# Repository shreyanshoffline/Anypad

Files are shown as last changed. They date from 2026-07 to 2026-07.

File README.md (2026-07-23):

# The Anypad ♾️

A custom left-hand gaming macropad that *actually* respects your muscle memory. Built for the Hack Club Hackpad program.

flag-orpheus-left

Most macropads use a rigid ortholinear grid, which is terrible for gaming. If you try to play Minecraft, Fortnite, or Roblox on a square grid, your fingers get confused because normal keyboards have a staggered layout. 

**The Anypad** fixes this. It features a true QWERTY-accurate 0.25U stagger for the WASD movement cluster, a dedicated thumb spacebar, and stacked pinky keys for Shift/Ctrl. Add an OLED screen, a rotary encoder, and an aggressive amount of RGB, and you have the ultimate mini-pad designed to seamlessly swap between gaming, office, and study modes.

>[!CAUTION]
>Below will be very revoulutionary designs and technology that is game-changing, literally

## 📸 The Screenshots

These are some screenshots of the PCB, Schematic, Case, And Complete Build.

### Overall Hackpad
Overall Hackpad

*(Note: Coming soon! After Build)*

### Schematic
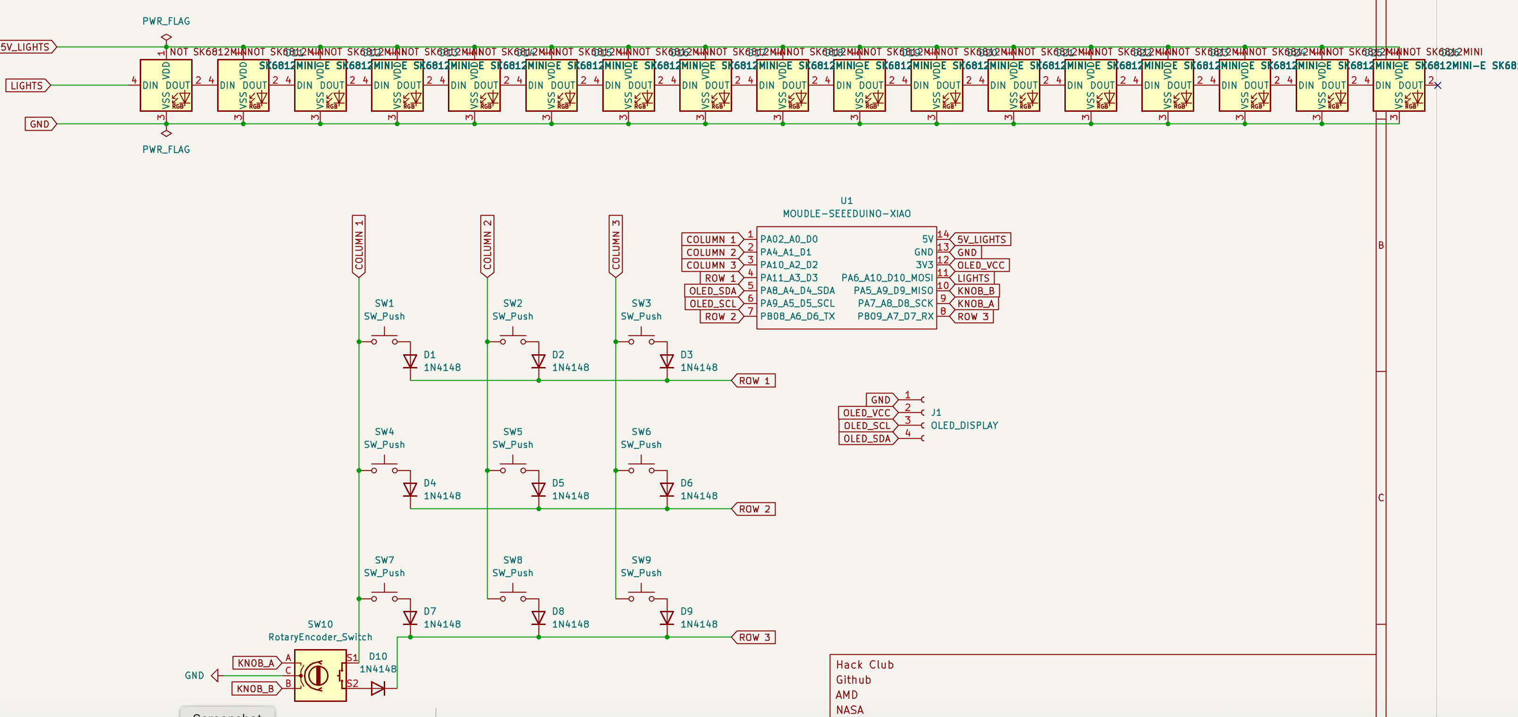
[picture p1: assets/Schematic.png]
Schematic


### PCB Layout
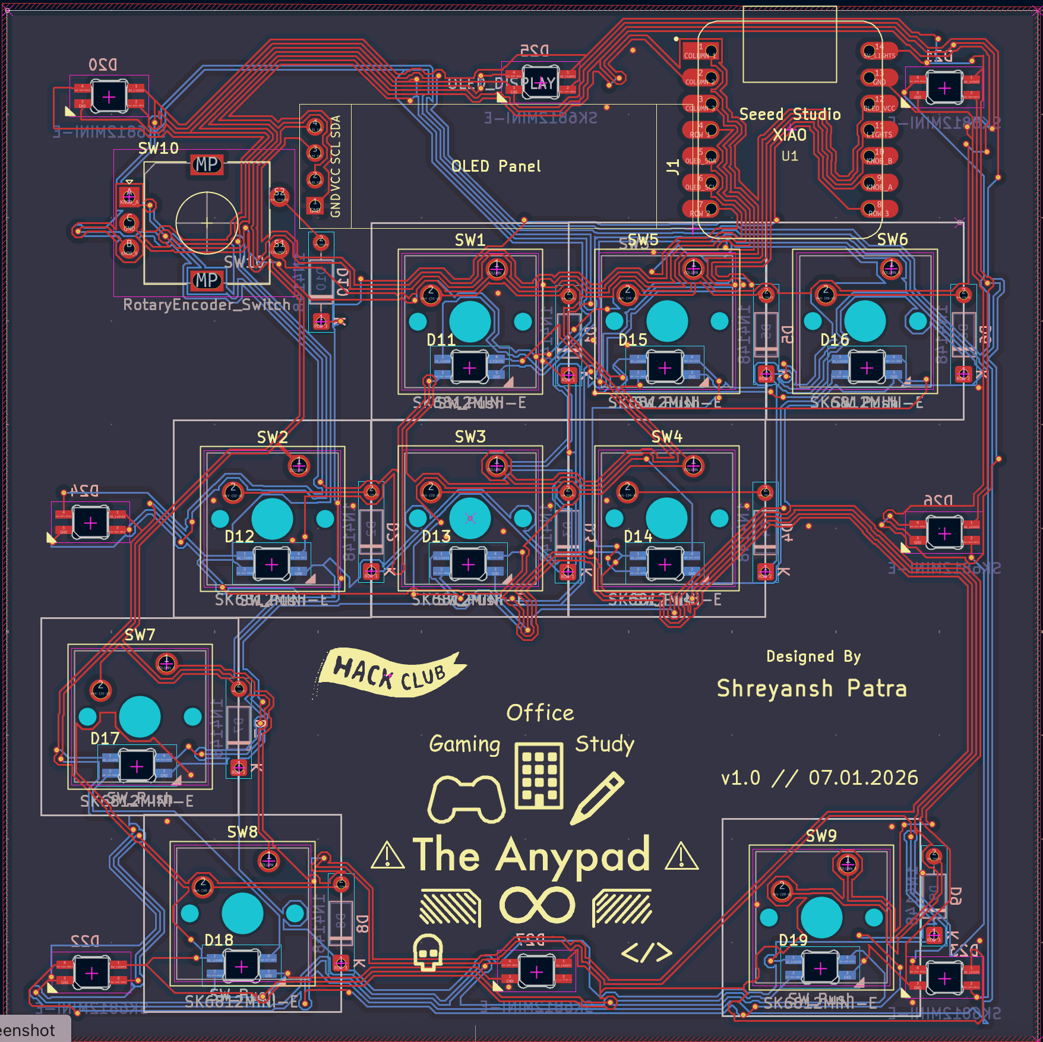
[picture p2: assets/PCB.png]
PCB Layout

>[!NOTE]
>Check out the silkscreen art

### CAD in Fusion360
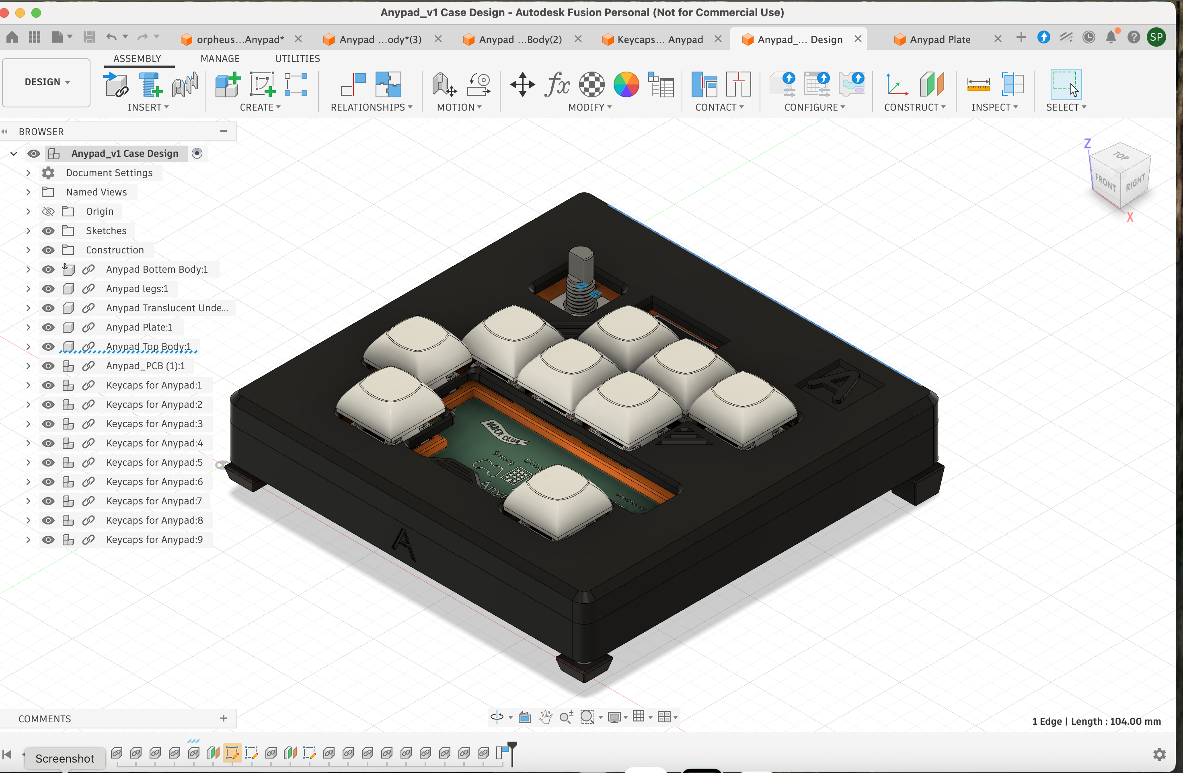
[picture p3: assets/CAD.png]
Case Assembly


---

## ✨ Features
* **Muscle-Memory Layout:** 9 mechanical switches arranged with realistic desktop stagger so you don't miss inputs mid-game or while locked in during work.
* **The Brain:** Powered by The Seeed Studio XIAO RP2040 Microcontroller. Small, But Mighty
* **The Screen:** A 0.91" OLED display to give visual feedback on your current active profile (Gaming 🎮 / Office 🏢 / Study ✏️).
* **The Knob** Instead of using keys to switch inventory slots, or raise and reduce volume the knob allows you to do more while taking less space.

## ✅ Benefits
* **Light, Small, Fast:** Instead of carrying an entire keyboard all you need is a mouse and The Anypad. Easily portable and gives you more desk space.
* **Focus, Study, Game:** Switch between focus modes in the swift turn of a knob. Quickly immerse your self in the gaming world or into optimized work and study shortcuts
* **RGB Everything:** 17 total SK6812 MINI-E addressable LEDs (9 per-key backlights + 8 corner underglows for a seamless desk halo effect). Instantly turns up your vibe
* **Ergonomics Over Symmetry:** The Anypad prioritizes hand comfort over artificial symmetry. While the layout might look like an unusual angle at first glance, it naturally aligns with where your fingers want to rest during long gaming sessions.

## </> Firmware Overview
The Anypad uses QMK for everything

>[!NOTE]
> Via will be added soon for instant flashing and customization

## 🧰 Bill of Materials (BOM)

| Component | Qty | Description |
| :--- | :---: | :--- |
| Seeed XIAO RP2040 | 1 | The Brains of the system, A Mighty little Microcontroller |
| EC11 Rotary Encoder | 1 | Rotating knob, with push-button functionality |
| Encoder Knob | 1 | Fits over the EC11 shaft |
| 0.91" OLED Display | 1 | Standard 4-pin breakout (GND, VCC, SCL, SDA) |
| Reverse Mount SK6812 MINI-E LEDs | 17 | 9 for Keys, 8 for bottom underglow |
| Through-Hole 1N4148 Diodes | 9 | For the 3x3 anti-ghosting matrix |
| Custom PCB (In /PCB)| 1 | Holds and connects all electrical components |
| Custom 3D Printed Case (In /Production)| 1 | Top plate + bottom enclosure |
| Blank White DSA Keycaps | 9 | 1U caps, Smooth and blank |
| MX-Style Keyswitches | 9 | The Nice Clicky Kind |
| M3x16mm screws | 4 | Tiny Screws That hold everything together |
| M3x5mx4mm Brass Heatset Inserts | 4 | Brass treads that makes the case re-openable |
>[!NOTE]
> You may also need a solder, soldering iron and other soldering accessories for completing the build

>[!TIP]
> You can get all the materials for free or bundled from the Hackpad Kit by Hack club. 

## 🧠 Behind the Hardware (The Wiring Matrix)

To make everything fit on the XIAO's extremely limited edge pins, the 9 keys are wired into a standard 3x3 diode matrix (using only 6 pins). 

This is a basic efficient layout that frees up the remaining pins perfectly for the OLED (2 pins), the Rotary Encoder (2 pins), and a single data line chained through all 17 LEDs without needing to resort to hidden pads or larger microcontrollers. 

---
> Designed by [shreyanshoffline](https://github.com/shreyanshoffline) for The Stardance Challenge by Hack Club, NASA, AMD, and Github.

unnamed

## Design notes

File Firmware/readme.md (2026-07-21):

# The Anypad

the_anypad

*A short description of the keyboard/project*

* Keyboard Maintainer: [Shreyansh Patra](https://github.com/shreyanshoffline)
* Hardware Supported: *The PCBs, controllers supported*
* Hardware Availability: *Links to where you can find this hardware*

Make example for this keyboard (after setting up your build environment):

    make the_anypad:default

Flashing example for this keyboard:

    make the_anypad:default:flash

See the [build environment setup](https://docs.qmk.fm/#/getting_started_build_tools) and the [make instructions](https://docs.qmk.fm/#/getting_started_make_guide) for more information. Brand new to QMK? Start with our [Complete Newbs Guide](https://docs.qmk.fm/#/newbs).

## Bootloader

Enter the bootloader in 3 ways:

* **Bootmagic reset**: Hold down the key at (0,0) in the matrix (usually the top left key or Escape) and plug in the keyboard
* **Physical reset button**: Briefly press the button on the back of the PCB - some may have pads you must short instead
* **Keycode in layout**: Press the key mapped to `QK_BOOT` if it is available

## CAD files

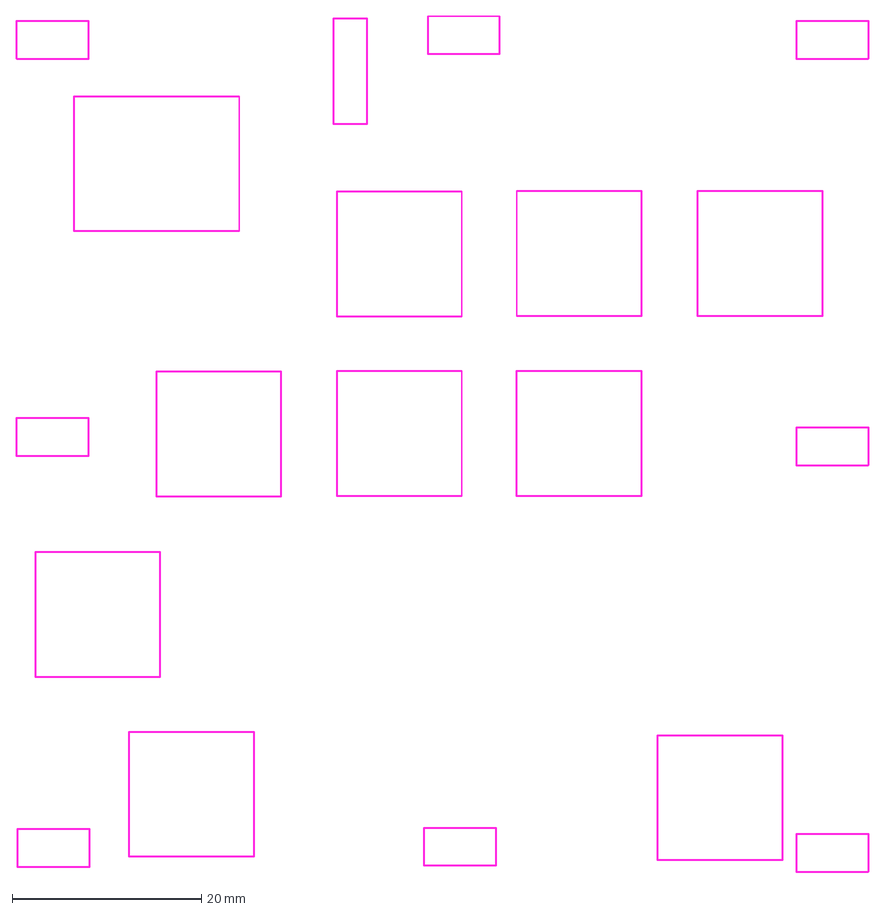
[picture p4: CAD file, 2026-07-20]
PCB/Drawings, Diagrams, and 3d Files of PCB/Anypad-F_Courtyard.dxf
90.2 x 90.5 mm

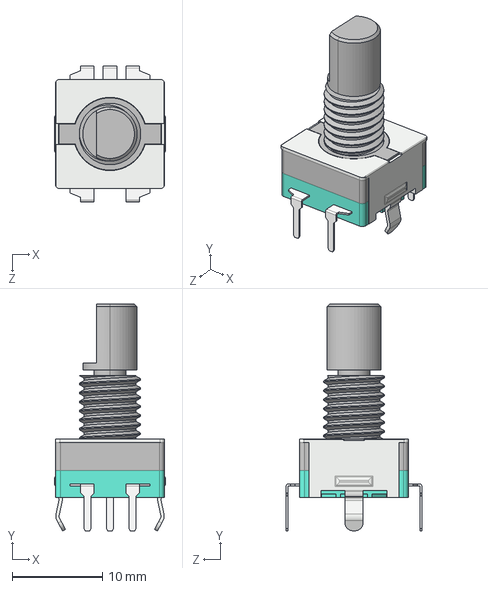
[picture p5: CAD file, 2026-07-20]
PCB/Files for 3d viewer/EC11_Rotary_Encoder.STEP
12.3 x 25.1 x 15.0 mm

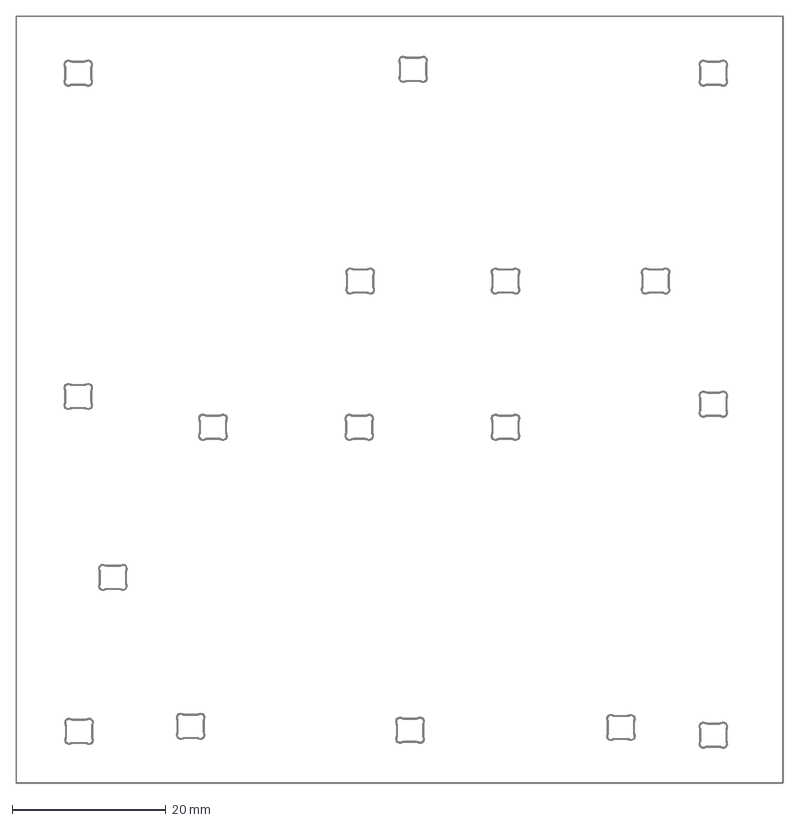
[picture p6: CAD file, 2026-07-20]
PCB/Drawings, Diagrams, and 3d Files of PCB/Anypad-Edge_Cuts.dxf
99.6 x 99.6 mm

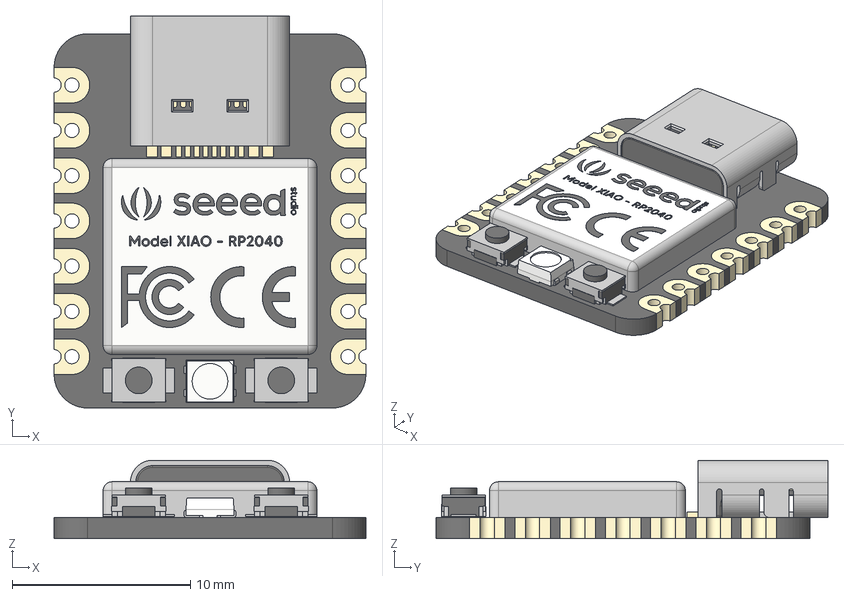
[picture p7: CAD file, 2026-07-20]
PCB/Files for 3d viewer/Seeed Studio XIAO RP2040 v26.step
17.5 x 22.0 x 4.40 mm
type-c v2
smd_button v3
DOUT
DIN
VSS
VDD
smd_button v3(Mirror)

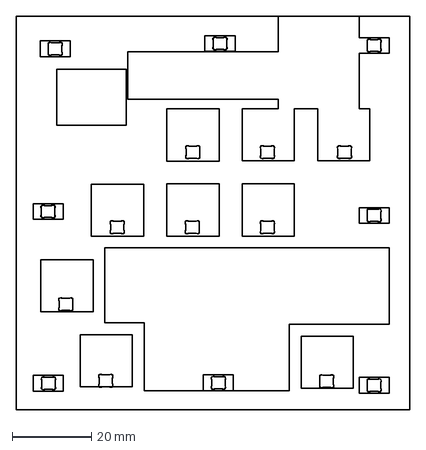
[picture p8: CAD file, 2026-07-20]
PCB/Drawings, Diagrams, and 3d Files of PCB/Anypad_Plate.dxf
99.6 x 99.6 mm

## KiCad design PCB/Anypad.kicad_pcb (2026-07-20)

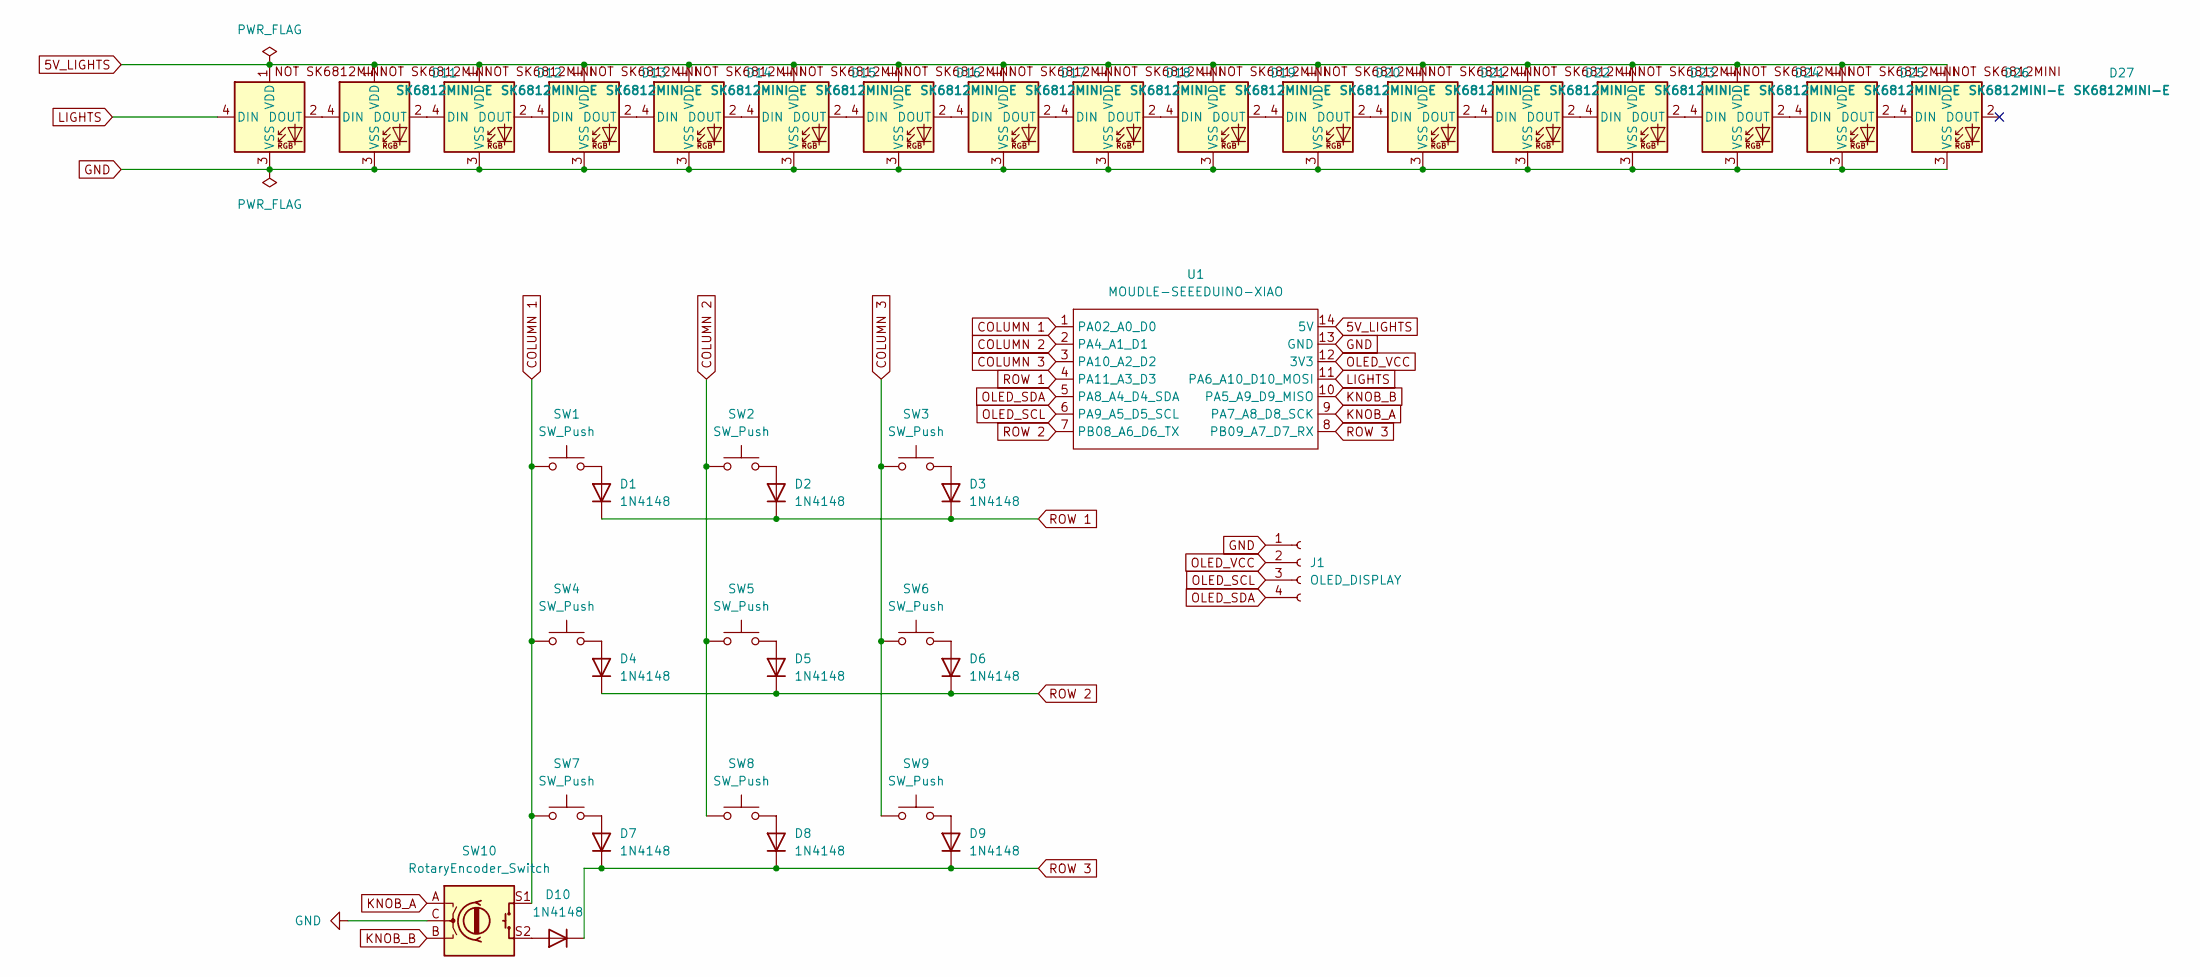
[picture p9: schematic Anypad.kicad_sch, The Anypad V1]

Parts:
D1, D2, D3, D4, D5, D6, D7, D8, D9, D10: 1N4148; D_DO-35_SOD27_P7.62mm_Horizontal
D11, D12, D13, D14, D15, D16, D17, D18, D19, D20, D21, D22, D23, D24, D25, D26, D27: SK6812MINI-E; SK6812MINI-E_fixed
J1: OLED_DISPLAY; SSD1306-0.91-OLED-4pin-128x32
SW1, SW2, SW3, SW4, SW5, SW6, SW7, SW8, SW9: SW_Push; SW_Cherry_MX_1.00u_PCB
SW10: RotaryEncoder_Switch; RotaryEncoder_Alps_EC11E-Switch_Vertical_H20mm
U1: MOUDLE-SEEEDUINO-XIAO; XIAO-Generic-Hybrid-14P-2.54-21X17.8MM

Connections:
5V_LIGHTS: D11.1 (VDD), D12.1 (VDD), D13.1 (VDD), D14.1 (VDD), D15.1 (VDD), D16.1 (VDD), D17.1 (VDD), D18.1 (VDD), D19.1 (VDD), D20.1 (VDD), D21.1 (VDD), D22.1 (VDD), D23.1 (VDD), D24.1 (VDD), D25.1 (VDD), D26.1 (VDD), D27.1 (VDD), U1.14 (5V)
COLUMN 1: SW1.1, SW4.1, SW7.1, SW10.S1, U1.1 (PA02_A0_D0)
COLUMN 2: SW2.1, SW5.1, SW8.1, U1.2 (PA4_A1_D1)
COLUMN 3: SW3.1, SW6.1, SW9.1, U1.3 (PA10_A2_D2)
GND: D11.3 (VSS), D12.3 (VSS), D13.3 (VSS), D14.3 (VSS), D15.3 (VSS), D16.3 (VSS), D17.3 (VSS), D18.3 (VSS), D19.3 (VSS), D20.3 (VSS), D21.3 (VSS), D22.3 (VSS), D23.3 (VSS), D24.3 (VSS), D25.3 (VSS), D26.3 (VSS), D27.3 (VSS), J1.1, SW10.C, U1.13 (GND)
KNOB_A: SW10.A, U1.9 (PA7_A8_D8_SCK)
KNOB_B: SW10.B, U1.10 (PA5_A9_D9_MISO)
LIGHTS: D11.4 (DIN), U1.11 (PA6_A10_D10_MOSI)
unnamed: D1.2 (A), SW1.2
unnamed: D2.2 (A), SW2.2
unnamed: D3.2 (A), SW3.2
unnamed: D4.2 (A), SW4.2
unnamed: D5.2 (A), SW5.2
unnamed: D6.2 (A), SW6.2
unnamed: D7.2 (A), SW7.2
unnamed: D8.2 (A), SW8.2
unnamed: D9.2 (A), SW9.2
unnamed: D10.2 (A), SW10.S2
unnamed: D11.2 (DOUT), D12.4 (DIN)
unnamed: D12.2 (DOUT), D13.4 (DIN)
unnamed: D13.2 (DOUT), D14.4 (DIN)
unnamed: D14.2 (DOUT), D15.4 (DIN)
unnamed: D15.2 (DOUT), D16.4 (DIN)
unnamed: D16.2 (DOUT), D17.4 (DIN)
unnamed: D17.2 (DOUT), D18.4 (DIN)
unnamed: D18.2 (DOUT), D19.4 (DIN)
unnamed: D19.2 (DOUT), D20.4 (DIN)
unnamed: D20.2 (DOUT), D21.4 (DIN)
unnamed: D21.2 (DOUT), D22.4 (DIN)
unnamed: D22.2 (DOUT), D23.4 (DIN)
unnamed: D23.2 (DOUT), D24.4 (DIN)
unnamed: D24.2 (DOUT), D25.4 (DIN)
unnamed: D25.2 (DOUT), D26.4 (DIN)
unnamed: D26.2 (DOUT), D27.4 (DIN)
OLED_SCL: J1.3, U1.6 (PA9_A5_D5_SCL)
OLED_SDA: J1.4, U1.5 (PA8_A4_D4_SDA)
OLED_VCC: J1.2, U1.12 (3V3)
ROW 1: D1.1 (K), D2.1 (K), D3.1 (K), U1.4 (PA11_A3_D3)
ROW 2: D4.1 (K), D5.1 (K), D6.1 (K), U1.7 (PB08_A6_D6_TX)
ROW 3: D7.1 (K), D8.1 (K), D9.1 (K), D10.1 (K), U1.8 (PB09_A7_D7_RX)

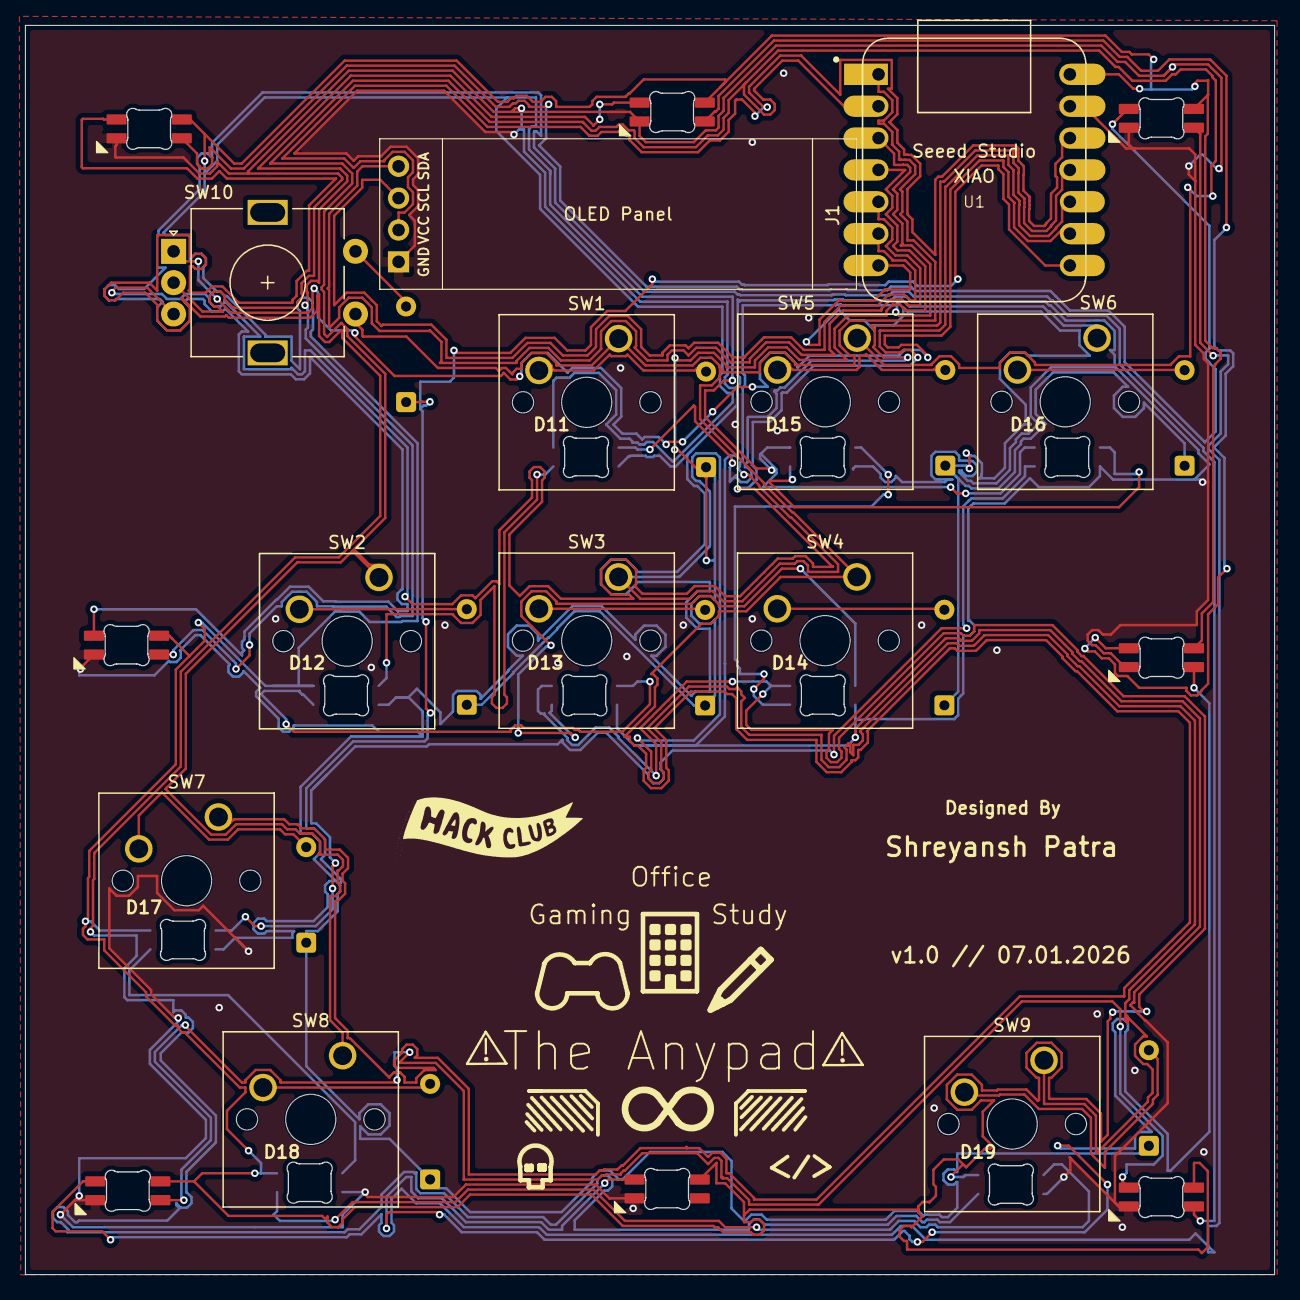
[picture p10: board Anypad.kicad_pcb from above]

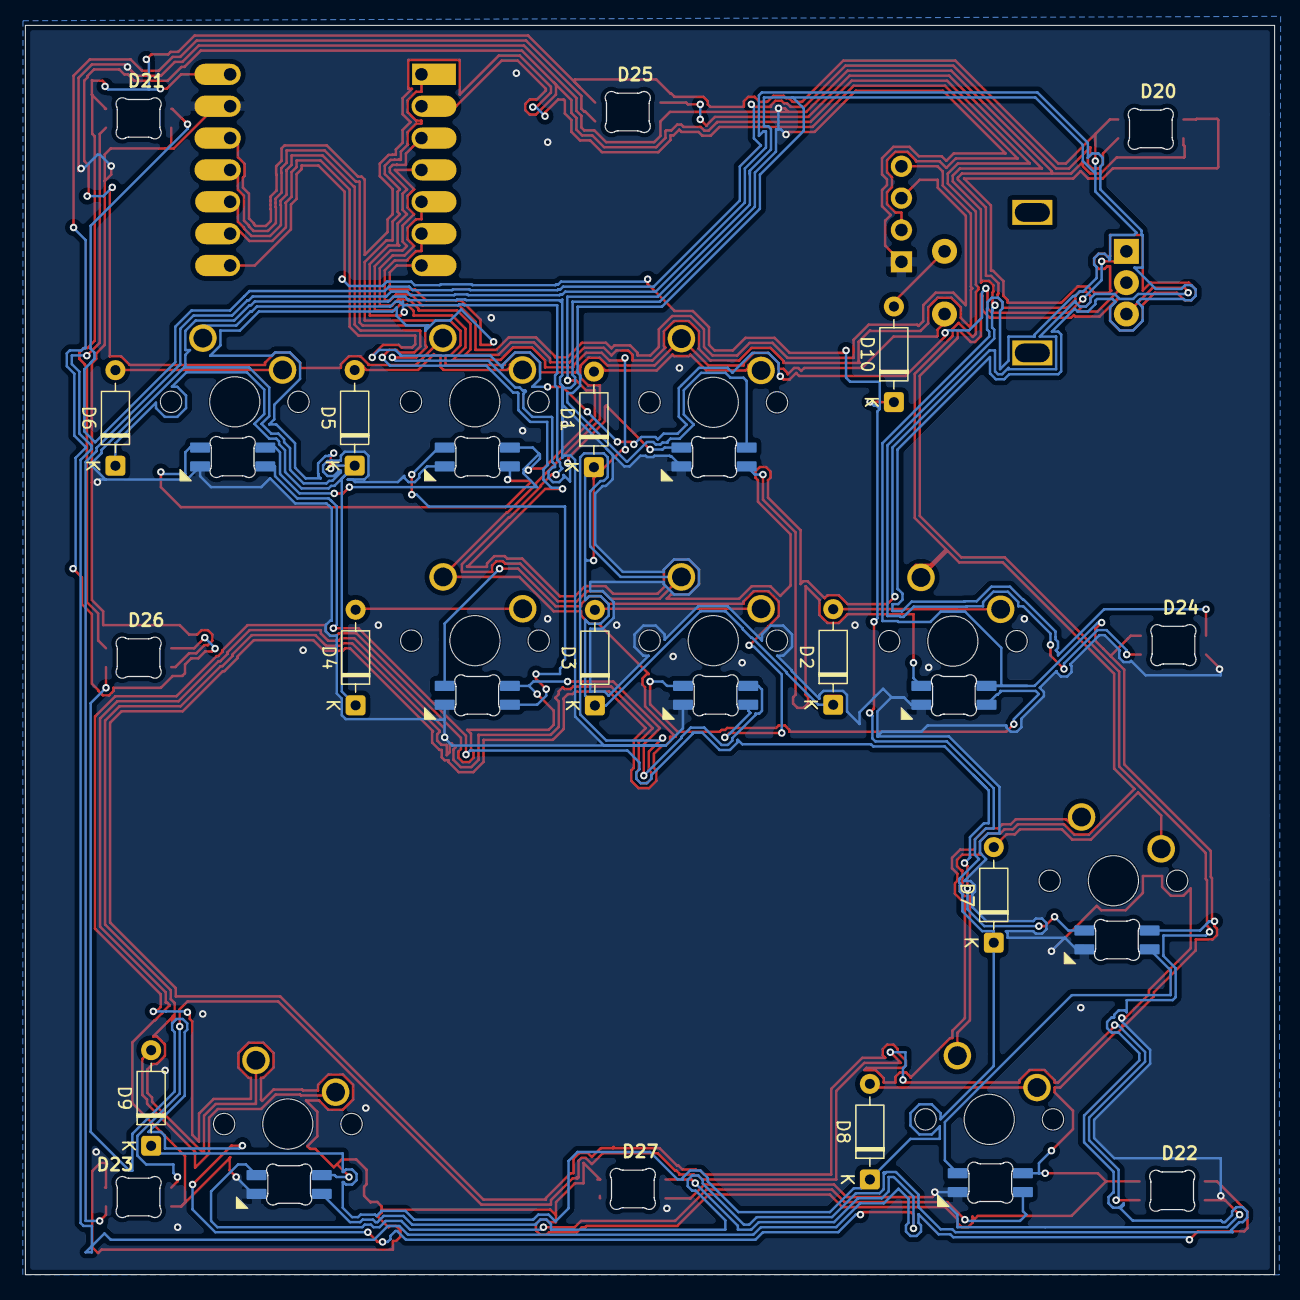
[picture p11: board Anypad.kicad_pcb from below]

Board: 2 copper layers, 99.6 x 99.6 mm, 39 parts (18 on the bottom side), 40 nets.

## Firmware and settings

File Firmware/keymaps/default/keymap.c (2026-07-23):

// Copyright 2026 Shrey Industries
// SPDX-License-Identifier: GPL-2.0-or-later

#include QMK_KEYBOARD_H
#include "animation.h" // Boot animation header

// --- ANIMATION BRIDGE (Resolves symbol mismatches with animation.h) ---
#define anim_frames       frame_allArray
#define TOTAL_ANIM_FRAMES frame_allArray_LEN

// Frame delays in ms (~67ms per frame = 15 FPS across 26 frames)
const uint16_t PROGMEM frame_delays[] = {
    100, 100, 100, 100, 100, 100, 100, 100, 100, 100,
    100, 100, 100, 100, 100, 100, 100, 175, 100, 100,
    100, 100, 100, 100, 100, 200
};

#define OLED_FRAME_BYTES ((128 * 32) / 8)  // width * height / 8 bits-per-byte

// --- LAYERS ---
enum layer_names {
    _OFFICE,
    _STUDY,
    _GAME,
    _SETTINGS
};

// --- CUSTOM KEYCODES ---
enum custom_keycodes {
    AP_GITHUB = SAFE_RANGE,
    AP_VSCODE,
    AP_PORTAL,
    AP_UNDERGLOW,
    AP_LIGHTMATRIX,
    AP_OLEDDISPLAY
};

// --- OLED STYLES ---
typedef enum {
    OLED_STYLE_MENU,      // Default menu list
    OLED_STYLE_VERTICAL,  // Compact vertical layout
    OLED_STYLE_STATS,     // Minimalist stats view
    OLED_STYLE_COUNT      // Total available styles
} oled_style_t;

// --- STATE VARIABLES ---
static bool is_animating_boot = true;
static uint16_t frame_timer = 0;
static uint8_t current_anim_frame = 0;

static bool is_encoder_pressed = false;
static oled_style_t current_oled_style = OLED_STYLE_MENU;

/*
 * PURE ELECTRICAL MATRIX LAYOUT (0-indexed for QMK / 1-indexed in KiCad):
 * Row 0: (0,0) [KiCad R1,C1] | (0,1) [KiCad R1,C2] | (0,2) [KiCad R1,C3]
 * Row 1: (1,0) [KiCad R2,C1] | (1,1) [KiCad R2,C2] | (1,2) [KiCad R2,C3]
 * Row 2: (2,0) [KiCad R3,C1] | (2,1) [KiCad R3,C2] | (2,2) [KiCad R3,C3]
 */

const uint16_t PROGMEM keymaps[][MATRIX_ROWS][MATRIX_COLS] = {
    [_OFFICE] = LAYOUT_anypad(
        LGUI(KC_C), LGUI(KC_N), LGUI(KC_F), // Row 0
        LGUI(KC_V), LGUI(KC_Z), LSFT(LGUI(KC_Z)), // Row 1 -- macOS Redo: Cmd+Shift+Z
        AP_VSCODE,  AP_GITHUB, LGUI(KC_S)  // Row 2
    ),

    [_STUDY] = LAYOUT_anypad(
        LGUI(KC_C), LGUI(KC_X), LGUI(KC_F), // Row 0
        LGUI(KC_V), LGUI(KC_Z), LSFT(LGUI(KC_Z)), // Row 1 -- macOS Redo: Cmd+Shift+Z
        AP_PORTAL,  LSFT(LGUI(KC_T)), LGUI(KC_S)  // Row 2
    ),

    [_GAME] = LAYOUT_anypad(
        KC_W,    KC_A,    KC_S,   // Row 0
        KC_D,    KC_E,    KC_R,   // Row 1
        KC_LSFT, KC_LCTL, KC_SPC  // Row 2
    ),

    [_SETTINGS] = LAYOUT_anypad(
        AP_UNDERGLOW, KC_NO,          KC_NO,          // Row 0
        KC_NO,        AP_LIGHTMATRIX, AP_OLEDDISPLAY, // Row 1
        KC_NO,        KC_NO,          KC_NO           // Row 2
    ),
};

// --- PROCESS KEYPRESSES & MACROS ---
bool process_record_user(uint16_t keycode, keyrecord_t *record) {
    if (record->event.key.row == 2 && record->event.key.col == 0) {
        is_encoder_pressed = record->event.pressed;
    }

    if (record->event.pressed) {
        switch (keycode) {
            case AP_GITHUB:
                SEND_STRING(SS_LGUI("t") "github.com" SS_TAP(X_ENTER));
                return false;
            case AP_VSCODE:
                SEND_STRING(SS_LGUI(" ") "Visual Studio Code" SS_TAP(X_ENTER));
                return false;
            case AP_PORTAL:
                SEND_STRING(SS_LGUI("t") "myolsd.us" SS_TAP(X_ENTER));
                return false;

            case AP_UNDERGLOW:
                #ifdef RGB_MATRIX_ENABLE
                    rgb_matrix_toggle();
                #endif
                return false;

            case AP_LIGHTMATRIX:
                #ifdef RGB_MATRIX_ENABLE
                    rgb_matrix_step();
                #endif
                return false;

            case AP_OLEDDISPLAY:
                #ifdef OLED_ENABLE
                    current_oled_style = (oled_style_t)((current_oled_style + 1) % OLED_STYLE_COUNT);
                    oled_clear();
                #endif
                return false;
        }
    }
    return true;
}

// --- ROTARY ENCODER CONTROLS ---
bool encoder_update_user(uint8_t index, bool clockwise) {
    (void)index;

    uint8_t current_layer = get_highest_layer(layer_state);

    if (is_encoder_pressed) {
        if (clockwise) {
            layer_move((current_layer + 1) % 4);
        } else {
            layer_move((current_layer + 3) % 4);
        }
        return false;
    }

    if (current_layer == _GAME) {
        tap_code(clockwise ? MS_WHLD : MS_WHLU);
    } else if (current_layer == _SETTINGS) {
        #ifdef RGB_MATRIX_ENABLE
            clockwise ? rgb_matrix_increase_hue() : rgb_matrix_decrease_hue();
        #endif
    } else {
        tap_code(clockwise ? KC_VOLU : KC_VOLD);
    }

    return false;
}

// --- OLED DISPLAY DRIVER ---
#ifdef OLED_ENABLE
oled_rotation_t oled_init_user(oled_rotation_t rotation) {
    return OLED_ROTATION_180;
}
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

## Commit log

2026-07-20 Folder organization
    [Anypad-Edge_Cuts.dxf, Anypad-F_Courtyard.dxf, Anypad.kicad_pcb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]
2026-07-20 Added Cad FIle
2026-07-20 Update README with Bill of Materials section
    Added a new section for the Bill of Materials with details on components used.
2026-07-23 Refactor code structure for improved readability and maintainability
    [Anypad-B_Cu.gbl, Anypad-B_Mask.gbs, Anypad-B_Silkscreen.gbo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]
